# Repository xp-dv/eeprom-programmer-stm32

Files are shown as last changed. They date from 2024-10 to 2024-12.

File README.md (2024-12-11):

# UART-Controlled AT28C16 EEPROM Programmer
This project is a UART-controlled AT28C16 EEPROM programmer based on the STM32 NUCLEO-F303K8 microcontroller.

## Team Members and Responsibilities
As a solo project, I was solely responsible for planning, designing, parts procurement, programming, prototyping, testing, and documenting.

## Command Set
The device is controlled via commands sent through UART via the NUCLEO-F303K8's micro-USB port. These commands are used to call the functions that read and write data to the EEPROM.

|Command|Function|
|:-|:-|
|a \<address\> | Read memory from \<address\> |
|b \<address\> \<byte\> | Write \<byte\> to \<address\> |
|r \<start\> \<end\> | Read memory from address \<start\> to \<end\> |
|w \<start\> \<end\> \<data\> | Write memory from address \<start\> to \<end\> with \<data\> |

> \< \> = Required

### Packet Format
* The maximum packet size is 256 data bytes + 1 packet terminator byte.
* All packets must end with the line feed (LF) character (`'\n'` or 0x0A) which serves as the packet terminator.
* All bytes (command keywords, addresses, and data) sent over UART must be one of these ASCII characters: `'0'` to `'9'`, `'a'` to `'z'`, or `'A'` to `'Z'`.
* All numbers (addresses and data bytes) must be sent in ASCII-coded hex.
* Addresses (0x000-0x7FF) must be represented using three characters, and EEPROM data (0x00-0xFF) must be represented using two characters.
* Every separate piece of data (individual addresses and individual data bytes) must be separated by spaces (`' '` or 0x20).

### Standard Operating Procedure
1. Commands must be sent as a single ASCII character corresponding to one of the commands in [Command Set](#command-set), followed by the packet terminator. This will put the device in ADDRESS mode, where it will wait to receive a valid address packet.
2. There are two address packet types: _single-address_ for commands `a` and `b` and _multi-address_ for commands `r` and `w`. A single-address packet must consist of a single-address, followed by the packet terminator. A multi-address packet must consist of a start and end address, separated by a space, then followed by the packet terminator. A valid received address packet will then put the device in DATA mode where it will wait to receive a valid data packet.
3. A valid data packet can include any number of two-character ASCII-coded hex bytes, as long as they match the address range specified in the address packet, are separated by spaces, and the packet ends with the packet terminator.
4. Upon receipt of a valid data packet, the device will perform the requested operation.

### Status Codes
Invalid packets will return one of the following status/error codes which is then translated to a string message that is sent to the user over UART.
|Code|Description|
|:-|:-|
| FA | UART_RX_EMPTY |
| FB | UART_RX_INVALID_FORMAT |
| FC | UART_RX_INVALID_DATA |
| FD | UART_RX_INVALID_RANGE |
| FE | UART_RX_INVALID_ADDRESS |
| FF | UART_RX_INVALID_INSTRUCTION |
| 00 | UART_RX_VALID_PACKET |
| 01 | UART_RX_VALID_DATA |

## Block Diagram
Block diagram of the intercommunication between the various devices required to build the EEPROM programmer.
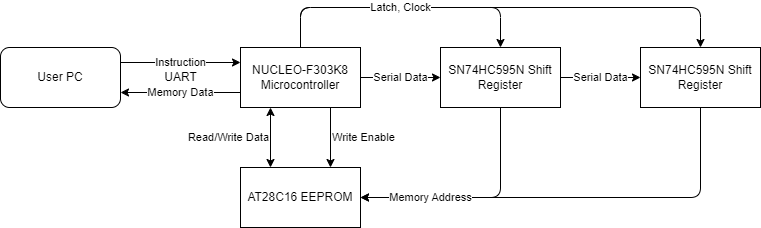
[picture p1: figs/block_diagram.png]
block_diagram


## Circular Buffer
A large portion of this project was dedicated to developing a circular buffer API that works in conjunction with the UART Rx callback and parsing functions to buffer any received characters while the device takes time to read/write data to the EEPROM.
This was a difficult task that proved to be quite a challenge as I was not experienced in encapsulation and file scoping practices when I first started working on it.
The circular buffer uses a head and tail pointer along with a UART interrupt to independently queue and dequeue characters from a 767-byte character buffer. This size buffer allows the user to buffer up to a full packet of ASCII-coded data while the device writes the previous packet.
The circular architecture of the buffer prevents memory from being written outside of the allocated bounds of the buffer.

## EEPROM Circuit
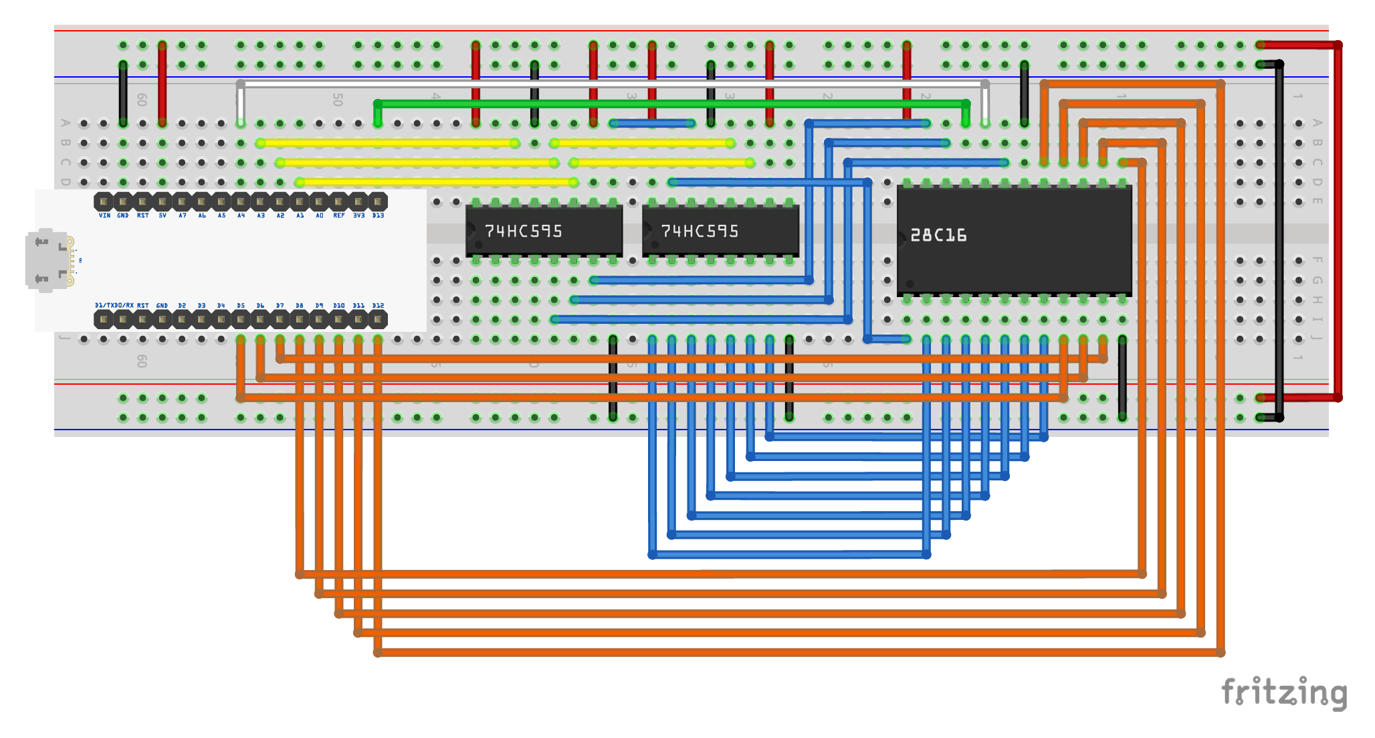
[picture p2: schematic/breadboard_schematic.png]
fritzing_schematic

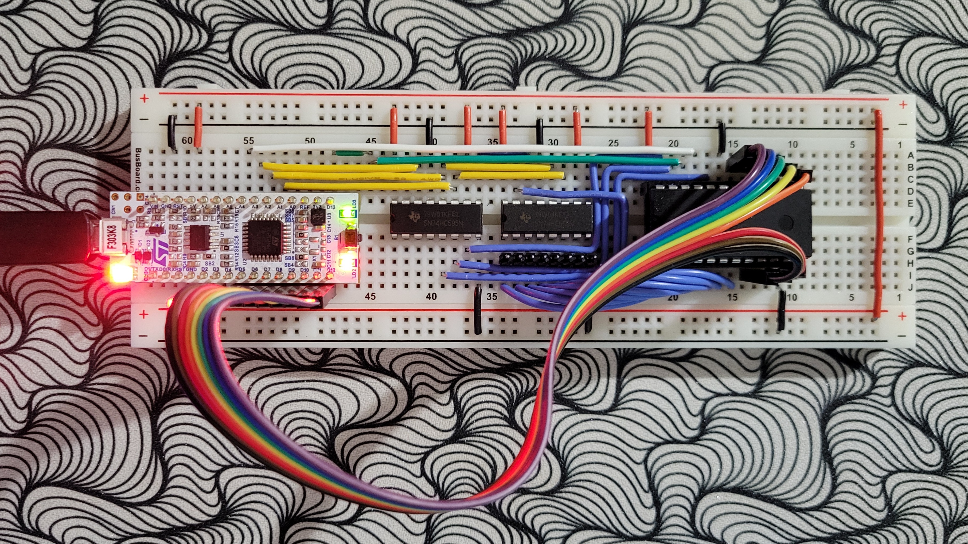
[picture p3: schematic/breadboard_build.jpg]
breadboard_build

> The AT28C16 EEPROM Programmer uses two serial shift registers for addressing and an 8-bit parallel data bus to enable full read and write of the AT28C16 EEPROM using minimal pins. These design choices allow the use of the small-footprint, breadboard-compatible NUCLEO-F303K8 microcontroller to operate the device with some pins to spare for additional functionality.

### Component List
* Micro-USB Cable (microcontroller to PC connection)
* STM32 NUCLEO-F303K8 Microcontroller
* 2 Shift Registers (SN74HC595N or equivalent)
* AT28C16 EEPROM
* 1 Breadboard or Perfboard (830+ tie-points)
* Jumper Wire and/or Ribbon Cable (21-26 AWG)

### AT28C16
The AT28C16 is a 16K-bit (2K x 8) parallel EEPROM designed for non-volatile data storage.
It operates on 5V and provides an addressable 11-bit address bus and 8-bit data bus for read and write operations.
Write operations are performed using the ~WE (Write Enable) and ~OE (Output Enable) pins according to the device's timing diagram, while the ~CE (Chip Enable) pin controls device selection.

### SN74HC595
The SN74HC595 is an 8-bit serial-in, parallel-out shift register with three-state output capabilities.
It operates on a supply voltage range of 2V to 6V.
Data is shifted into the device's storage register serially on the rising edge of the SRCLK (Shift Register Clock) and latched to the output pins on the rising edge of the RCLK (Register Clock). Outputs can be enabled or disabled using the ~OE (Output Enable) pin, allowing control over the parallel outputs.

## Test Cases
1. Instruction parser shall be robust enough to take any input, throwing errors if the instruction is formatted incorrectly.
2. Device successfully shifts the full 11-bit EEPROM address to the serial-in, parallel-out shift register.
3. Device pulses write enable pin within 100-1000 ns (from AT28C16 datasheet)
4. ‘a’ command correctly reads a single byte at the given EEPROM address
5. ‘r’ command correctly reads multiple bytes at the given block of EEPROM address
6. ‘b’ command correctly writes a single byte at the given EEPROM address
7. ‘w’ command correctly writes multiple bytes at the given block of EEPROM address

### Test Case 1
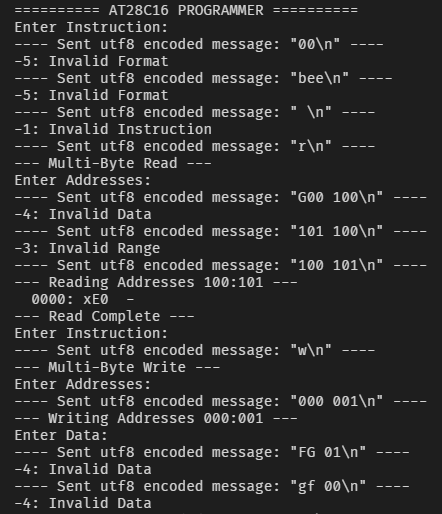
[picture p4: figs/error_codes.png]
error_codes

> Here, a wide range of error codes printed out to the user in different situations.

### Test Case 2
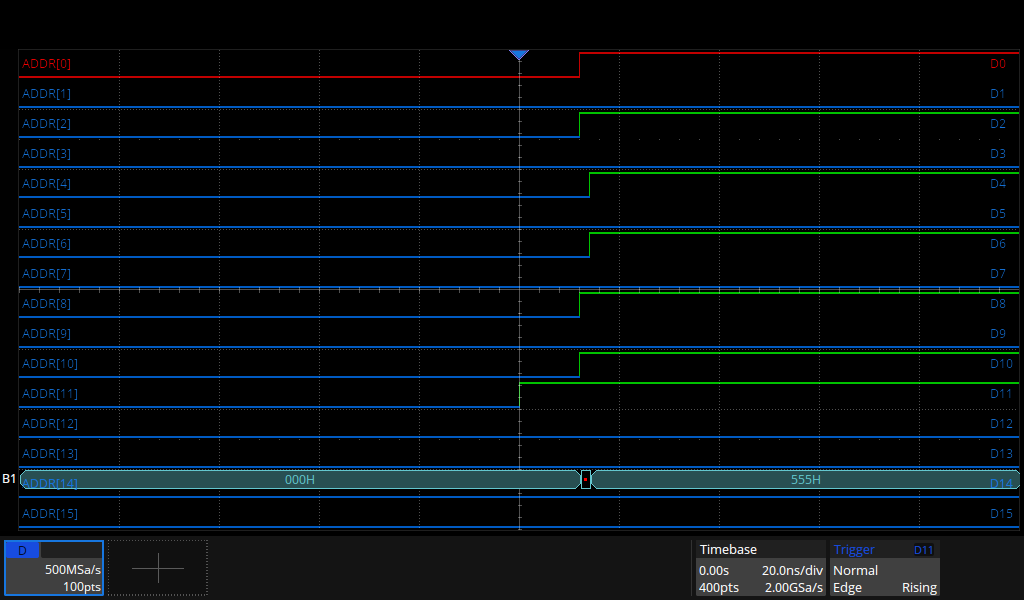
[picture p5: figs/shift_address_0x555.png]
shift_address_0x555

> The above logic analyzer capture of the parallel shift register demonstrates the device successfully shifting from address 0x000 to 0x555.

### Test Case 3
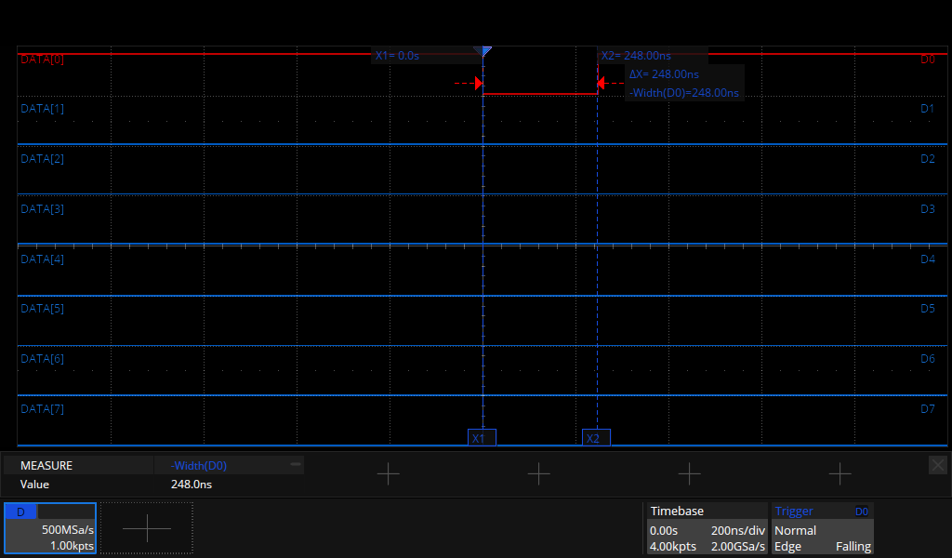
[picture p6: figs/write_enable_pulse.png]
write_enable_pulse

> The above logic analyzer capture of the Write Enable pin shows the write enable pulse width is 248ns which adequately falls between the 100-1000ns range specified by the EEPROM datasheet.

### Test Cases 4 & 5
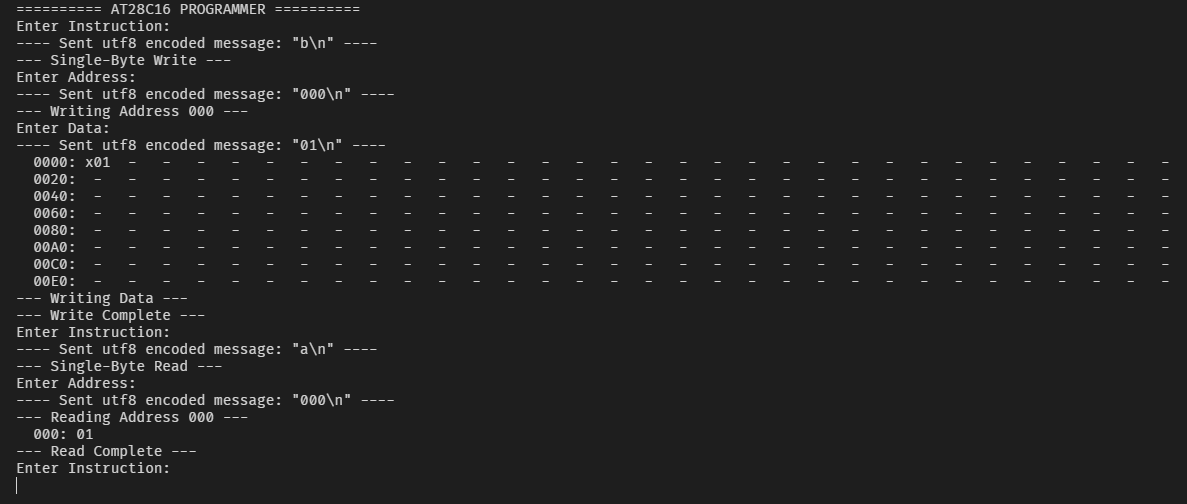
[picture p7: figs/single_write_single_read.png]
single_write_single_read

> The command `'b'` accepts the valid address 0x000 and the valid byte 0x01, then successfully writes that byte to address 0x000, as shown by the command `'a'` which successfully printed the value 0x01 for the byte at address 0x000.

### Test Cases 6 & 7
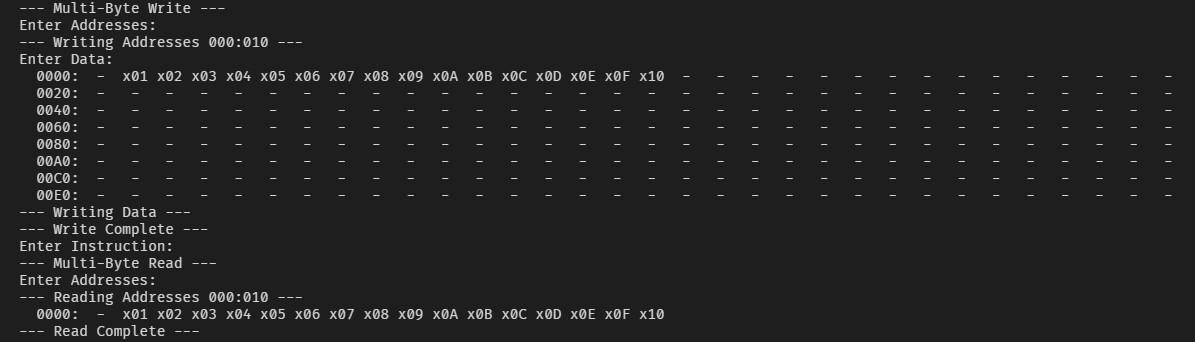
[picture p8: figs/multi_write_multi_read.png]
multi_write_multi_read

> The command `'w'` accepts the valid addresses 0x000 to 0x010 and the valid data 0x00 to 0x10, then successfully writes the data to the correct address range, as shown by the command `'r'` which successfully printed those values for addresses 0x000 to 0x010.

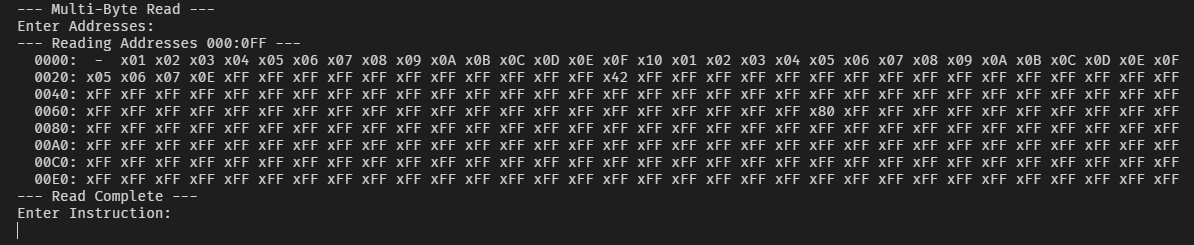
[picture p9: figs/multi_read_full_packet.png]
multi_read_full_packet

> Here, the command `'r'` prints the full 256-byte packet.

## Conclusion
This UART-controlled AT28C16 EEPROM programmer demonstrates a wide range of skills I obtained in this course.
Through the pin manipulation functions, I demonstrated knowledge of the GPIO register architecture, reading and writing to the registers directly rather than relying on the HAL library.
Through the test cases, I demonstrated my ability to use a logic analyzer to capture data and signals across multiple pins, analyzing their values and timing accuracy.
Through the circular buffer library and state machine loop, I demonstrated understanding of a common data structure in UART communication using both interrupts and polling.
While there are certainly improvements to be made, listed below, this project was an overall success as the device was able to pass all 7 desired test cases consistently.

## Future Improvements
* Allow for additional data packets to be sent over UART in succession rather than a single 256-byte packet per command call.
* Clear the data packet buffer to prevent residual data from being written.
* Add additional filtering to check if the given data matches the length of the addresses given.

## References
- [AT28C16 Datasheet](https://www.microchip.com/content/dam/mchp/documents/OTH/ProductDocuments/DataSheets/doc0258.pdf)
- [SN74HC595](https://www.ti.com/lit/ds/symlink/sn74hc595.pdf)
- [Circular Buffer Example](https://embeddedartistry.com/blog/2017/05/17/creating-a-circular-buffer-in-c-and-c/)

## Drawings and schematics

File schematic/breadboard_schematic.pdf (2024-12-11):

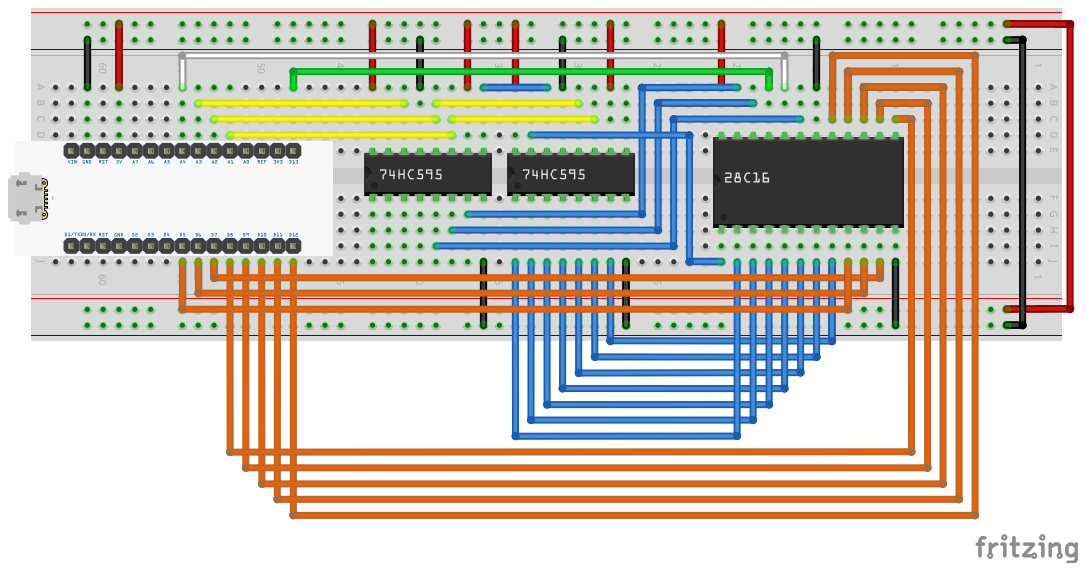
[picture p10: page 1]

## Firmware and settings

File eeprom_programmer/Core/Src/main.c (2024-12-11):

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
/* Includes ------------------------------------------------------------------*/
#include "main.h"

/* USER CODE BEGIN Includes */

#include "circ_buf.h"
#include "uart_rx.h"
#include "eeprom.h"
#include "pin_manipulation.h"
#include "print.h" // UART printf() and debugf()
#include <stdint.h>
#include <string.h>

/* USER CODE END Includes */

/* USER CODE BEGIN PTD */

typedef enum system_state {
  STARTUP_STATE,
  INSTRUCTION_STATE,
  ADDRESS_STATE,
  DATA_STATE,
  SINGLE_READ_STATE,
  SINGLE_WRITE_STATE,
  MULTI_READ_STATE,
  MULTI_WRITE_STATE,
} system_state_t;

/* USER CODE END PTD */

UART_HandleTypeDef huart2;

/* USER CODE BEGIN PV */

char printf_buffer[PRINTF_BUF_SIZE] = ""; // For print.h

uart_rx_handle_t uart_rx;
circ_buf_handle_t circ_buf;
eeprom_handle_t eeprom;

/* USER CODE END PV */

void SystemClock_Config(void);
static void MX_GPIO_Init(void);
static void MX_USART2_UART_Init(void);
/* USER CODE BEGIN PFP */

//* Private Helper Function Prototypes

static void print_status(uart_rx_status_t status);

/* USER CODE END PFP */

/* USER CODE BEGIN 0 */

//* State Event Handlers

system_state_t startup_state_handler(system_state_t system_state) {
  // Startup Delay
  HAL_Delay(500);

  // Startup Message
  uint8_t msg[UART_PACKET_SIZE] = "========== AT28C16 PROGRAMMER ==========\n";
  HAL_UART_Transmit(&huart2, (uint8_t*)msg, strlen((char*)msg), HAL_MAX_DELAY);

  // Init Circular Buffer Struct
  circ_buf = circ_buf_init(UART_PACKET_SIZE);

  // Init UART Rx Struct
  char delimiter = (char)' ';
  char terminator = (char)'\n';
  uart_rx = uart_rx_init(DATA_PACKET_SIZE, delimiter, terminator);

  // Init EEPROM Struct
  eeprom_t at28c16 = {
    .data_port = SHIFT_DATA_GPIO_Port,
    .data_pin = SHIFT_DATA_Pin,
    .clock_port = SHIFT_CLK_GPIO_Port,
    .clock_pin = SHIFT_CLK_Pin,
    .latch_port = SHIFT_LATCH_GPIO_Port,
    .latch_pin = SHIFT_LATCH_Pin,
    .mode = SINGLE_READ_MODE,
    .addresses = {0xFFF, 0xFFF},
  };
  eeprom = &at28c16;

  // UART Interrupt RX Setup
  HAL_UART_Receive_IT(&huart2, uart_rx_char(uart_rx), 1U);

  // Startup Delay
  HAL_Delay(500);

  printf("Enter Instruction:\n");
  return INSTRUCTION_STATE;
}

system_state_t instruction_state_handler(system_state_t system_state) {
  static uart_rx_status_t status = UART_RX_EMPTY;
  uart_rx_status_t new_status = uart_rx_parse_instruction(uart_rx, circ_buf);
  if (new_status == UART_RX_VALID_PACKET) {
    switch (uart_rx_instruction(uart_rx)) {
      case SINGLE_READ_INSTRUCTION:
        printf("--- Single-Byte Read ---\n");
        printf("Enter Address:\n");
        eeprom->mode = SINGLE_READ_MODE;
        return ADDRESS_STATE;
        break;

      case SINGLE_WRITE_INSTRUCTION:
        printf("--- Single-Byte Write ---\n");
        printf("Enter Address:\n");
        eeprom->mode = SINGLE_WRITE_MODE;
        return ADDRESS_STATE;
        break;

      case MULTI_READ_INSTRUCTION:
        printf("--- Multi-Byte Read ---\n");
        printf("Enter Addresses:\n");
        eeprom->mode = MULTI_READ_MODE;
        return ADDRESS_STATE;
        break;

      case MULTI_WRITE_INSTRUCTION:
        printf("--- Multi-Byte Write ---\n");
        printf("Enter Addresses:\n");
        eeprom->mode = MULTI_WRITE_MODE;
        return ADDRESS_STATE;
        break;

      default:
        new_status = UART_RX_INVALID_INSTRUCTION;
        print_status(new_status);
        break;
    }
  } else if ((new_status != UART_RX_EMPTY) && (new_status != status)) {
    print_status(new_status);
  }
  status = new_status;
  HAL_Delay(1000 / PACKET_POLLING_RATE);
  return INSTRUCTION_STATE;
}

system_state_t address_state_handler(system_state_t system_state) {
  static uart_rx_status_t status = UART_RX_EMPTY;
  uart_rx_status_t new_status = uart_rx_parse_address(uart_rx, circ_buf, eeprom, status);
  if (new_status == UART_RX_VALID_PACKET) {
    if ((eeprom->addresses[0] <= EEPROM_ADDRESS_MAX) && (eeprom->addresses[1] <= EEPROM_ADDRESS_MAX)) {
      switch (eeprom->mode) {
        case SINGLE_READ_MODE:
          return SINGLE_READ_STATE;
          break;

        case SINGLE_WRITE_MODE:
          printf("--- Writing Address %03X ---\n", eeprom->addresses[0] % 0x1000);
          printf("Enter Data:\n");
          return DATA_STATE;
          break;

        case MULTI_READ_MODE:
          return MULTI_READ_STATE;
          break;

        case MULTI_WRITE_MODE:
          printf("--- Writing Addresses %03X:%03X ---\n", eeprom->addresses[0] % 0x1000, eeprom->addresses[1] % 0x1000);
          printf("Enter Data:\n");
          return DATA_STATE;
          break;

        default:
          printf("Enter Instruction:\n");
          return INSTRUCTION_STATE;
          break;
      }
    } else {
      new_status = UART_RX_INVALID_ADDRESS;
      print_status(new_status);
    }
  } else if ((new_status != UART_RX_EMPTY) && (new_status != status)) {
    print_status(new_status);
  }
  status = new_status;
  HAL_Delay(1000 / PACKET_POLLING_RATE);
  return ADDRESS_STATE;
}

system_state_t data_state_handler(system_state_t system_state) {
  static uart_rx_status_t status = UART_RX_EMPTY;
  uart_rx_status_t new_status = uart_rx_parse_data(uart_rx, circ_buf, status);
  if (new_status == UART_RX_VALID_PACKET) {
    dump_hex(uart_rx_packet(uart_rx), uart_rx_size(uart_rx), 0x20); /* UNIT_TEST */
    switch (eeprom->mode) {
      case SINGLE_WRITE_MODE:
        return SINGLE_WRITE_STATE;
        break;

      case MULTI_WRITE_MODE:
        return MULTI_WRITE_STATE;
        break;

      default:
        printf("Enter Instruction:\n");
        return INSTRUCTION_STATE;
        break;
    }
  } else if ((new_status != UART_RX_EMPTY) && (new_status != status)) {
    print_status(new_status);
  }
  status = new_status;
  HAL_Delay(1000 / PACKET_POLLING_RATE);
  return DATA_STATE;
}

system_state_t single_read_state_handler(system_state_t system_state) {
  printf("--- Reading Address %03X ---\n", eeprom->addresses[0] % 0x1000);

  single_read(eeprom);

  printf("--- Read Complete ---\n");
  printf("Enter Instruction:\n");
  return INSTRUCTION_STATE;
}

system_state_t single_write_state_handler(system_state_t system_state) {
  printf("--- Writing Data ---\n");

  single_write(eeprom, *uart_rx_packet(uart_rx));

  printf("--- Write Complete ---\n");
  printf("Enter Instruction:\n");
  return INSTRUCTION_STATE;
}

system_state_t multi_read_state_handler(system_state_t system_state) {
  // If out of range, return to ADDRESS_STATE
  if (eeprom->addresses[1] <= eeprom->addresses[0]) {
    print_status(UART_RX_INVALID_RANGE);
    return ADDRESS_STATE;
  }
  printf("--- Reading Addresses %03X:%03X ---\n", eeprom->addresses[0] % 0x1000, eeprom->addresses[1] % 0x1000);

  multi_read(eeprom);

  printf("--- Read Complete ---\n");
  printf("Enter Instruction:\n");
  return INSTRUCTION_STATE;
}

system_state_t multi_write_state_handler(system_state_t system_state) {
  // If out of range, return to ADDRESS_STATE
  if (eeprom->addresses[1] <= eeprom->addresses[0]) {
    print_status(UART_RX_INVALID_RANGE);
    return ADDRESS_STATE;
  }
  printf("--- Writing Data ---\n");

  multi_write(eeprom, uart_rx_packet(uart_rx));

  printf("--- Write Complete ---\n");
  printf("Enter Instruction:\n");
  return INSTRUCTION_STATE;
}

//* Private Helper Functions

static void print_status(uart_rx_status_t status) {
  char status_msg[64] = "";
  switch (status) {
    case UART_RX_EMPTY:
      sprintf(status_msg, "Empty");
      break;
    case UART_RX_INVALID_FORMAT:
      sprintf(status_msg, "Invalid Format");
      break;
    case UART_RX_INVALID_DATA:
      sprintf(status_msg, "Invalid Data");
      break;
    case UART_RX_INVALID_RANGE:
      sprintf(status_msg, "Invalid Range");
      break;
    case UART_RX_INVALID_ADDRESS:
      sprintf(status_msg, "Invalid Address");
      break;
    case UART_RX_INVALID_INSTRUCTION:
      sprintf(status_msg, "Invalid Instruction");
      break;
    case UART_RX_VALID_PACKET:
      sprintf(status_msg, "Valid Packet");
      break;
    case UART_RX_VALID_DATA:
      sprintf(status_msg, "Valid Data");
      break;
  }
  printf("%02d: %s\n", (int)status, (uint8_t*)status_msg);
}

/* USER CODE END 0 */

/**
  * @brief  The application entry point.
  * @retval int
  */
int main(void)
{

  /* MCU Configuration--------------------------------------------------------*/

  /* Reset of all peripherals, Initializes the Flash interface and the Systick. */
  HAL_Init();

  /* Configure the system clock */
  SystemClock_Config();

  /* Initialize all configured peripherals */
  MX_GPIO_Init();
  MX_USART2_UART_Init();
  /* USER CODE BEGIN 2 */

  //* Next State Variable
  system_state_t system_state = STARTUP_STATE;

  /* USER CODE END 2 */

  /* Infinite loop */
  /* USER CODE BEGIN WHILE */
  while (1) {
    /* USER CODE END WHILE */

    /* USER CODE BEGIN 3 */

    //* State Handlers
    // Perform functions for given state, then return the value of the next state
    switch (system_state) {
      case STARTUP_STATE:
        system_state = startup_state_handler(system_state);
        break;
      case INSTRUCTION_STATE:
        system_state = instruction_state_handler(system_state);
        break;
      case ADDRESS_STATE:
        system_state = address_state_handler(system_state);
        break;
      case DATA_STATE:
        system_state = data_state_handler(system_state);
        break;
      case SINGLE_READ_STATE:
        system_state = single_read_state_handler(system_state);
        break;
      case SINGLE_WRITE_STATE:
        system_state = single_write_state_handler(system_state);
        break;
      case MULTI_READ_STATE:
        system_state = multi_read_state_handler(system_state);
        break;
      case MULTI_WRITE_STATE:
        system_state = multi_write_state_handler(system_state);
        break;

      default:
        system_state = startup_state_handler(system_state);
        break;
    }
  }

  /* USER CODE END 3 */
}

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
/* USER CODE BEGIN 4 */

/**
 * @brief UART Interrupt Callback
 * @param huart HAL UART Structure handle
 */
void HAL_UART_RxCpltCallback(UART_HandleTypeDef *huart) {
  circ_buf_write_ov_byte(circ_buf, *(uart_rx_char(uart_rx)));

  // Reactivate UART Interrupt RX
  HAL_UART_Receive_IT(huart, uart_rx_char(uart_rx), 1U);
}

/* USER CODE END 4 */
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


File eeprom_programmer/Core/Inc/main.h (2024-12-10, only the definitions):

#define USE_FULL_ASSERT 1U
#define DATA_PACKET_SIZE 256U
#define ACH_SIZE 2U
#define UART_PACKET_SPACES (DATA_PACKET_SIZE - 1U)
#define UART_PACKET_SIZE (DATA_PACKET_SIZE * (ACH_SIZE + sizeof(char)))
#define PACKET_POLLING_RATE 4U // Hz
#define EEPROM_START_ADDRESS 0U
#define EEPROM_ADDRESS_SIZE 2048U // Bytes
#define EEPROM_ADDRESS_MAX (EEPROM_ADDRESS_SIZE - 1U) // Bytes
#define BAUD_RATE 9600
#define D7_Pin GPIO_PIN_0
#define D7_GPIO_Port GPIOF
#define D8_Pin GPIO_PIN_1
#define D8_GPIO_Port GPIOF
#define SHIFT_CLK_Pin GPIO_PIN_1
#define SHIFT_CLK_GPIO_Port GPIOA
#define VCP_TX_Pin GPIO_PIN_2
#define VCP_TX_GPIO_Port GPIOA
#define SHIFT_LATCH_Pin GPIO_PIN_3
#define SHIFT_LATCH_GPIO_Port GPIOA
#define SHIFT_DATA_Pin GPIO_PIN_4
#define SHIFT_DATA_GPIO_Port GPIOA
#define OUTPUT_ENABLE_Pin GPIO_PIN_5
#define OUTPUT_ENABLE_GPIO_Port GPIOA
#define D6_Pin GPIO_PIN_1
#define D6_GPIO_Port GPIOB
#define D9_Pin GPIO_PIN_8
#define D9_GPIO_Port GPIOA
#define D10_Pin GPIO_PIN_11
#define D10_GPIO_Port GPIOA
#define SWDIO_Pin GPIO_PIN_13
#define SWDIO_GPIO_Port GPIOA
#define SWCLK_Pin GPIO_PIN_14
#define SWCLK_GPIO_Port GPIOA
#define VCP_RX_Pin GPIO_PIN_15
#define VCP_RX_GPIO_Port GPIOA
#define WRITE_ENABLE_Pin GPIO_PIN_3
#define WRITE_ENABLE_GPIO_Port GPIOB
#define D12_Pin GPIO_PIN_4
#define D12_GPIO_Port GPIOB
#define D11_Pin GPIO_PIN_5
#define D11_GPIO_Port GPIOB
#define D5_Pin GPIO_PIN_6
#define D5_GPIO_Port GPIOB

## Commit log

2024-11-18 Created STM32 project and began pin assignments
2024-11-27 Finished pin assignments
2024-11-28 Created working VS Code compiler config for STM32
2024-11-28 Created UART interrupt Rx to circular buffer
    Needs troubleshooting. Device can't receive more than 8 characters at a time.
    Circular buffer is provided by my circ_buf library.
2024-11-28 Full UART data packet functionality
    TODO: Instruction packet functionality using uart_rx_read_byte and switch.
    TODO: State machine switch and handler functions.
2024-12-01 State handler w/ UART packet and instruction parsing.
    UART receives both data and instruction packets, returning the instruction state to the state handler.
    printf() is now redirected to HAL UART transmit through print.h
2024-12-10 Fully functional single_read and single_write over UART
    Added custom pin shift/read/write/mode functions to pin_manipulation.h & pin_manipulation.c. Added EEPROM functionality to eeprom.h & eeprom.c
2024-12-11 Added Fritzing breadboard schematic
    [breadboard_schematic.fzz]
2024-12-11 Added Fritzing breadboard schematic to README.md

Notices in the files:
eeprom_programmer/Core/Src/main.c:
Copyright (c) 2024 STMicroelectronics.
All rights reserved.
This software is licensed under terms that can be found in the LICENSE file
